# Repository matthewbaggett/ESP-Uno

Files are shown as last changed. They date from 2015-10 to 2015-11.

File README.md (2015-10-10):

# ESPUno - A dirty ESP8266 Arduino Uno clone

Using an ESP8266 should be fun! These processors are cheap enough to be disposable, lets make that easier to achieve as a hobbist.

Features: 

+ 80/160Mhz ESP8266
+ 5 working ADC pins (A0 is the 0-1 volt ESP8266 ADC, A1-A5 are provided by an i2c ADC controller (ADS1115) 
+ Pin 13 LED still present, tied to SCLK/GPIO6
+ LiPo cell support on-board! MCP73831 Charger circuit, TSP61200 Boost converter (shamelessly stolen from a [Sparkfun reference design](https://www.sparkfun.com/products/11231)) 
+ 3.3V regulator ([AMS1117](http://www.aliexpress.com/premium/ams1117.html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))
+ All the associated recommended pullups as per the [Arduino ESP8266 project](https://github.com/esp8266/Arduino) ([Schematic](https://github.com/esp8266/Arduino/blob/esp8266/docs/ESP_improved_stability.png))
+ Built-in USB programmer ([FTDI FT232R](http://www.aliexpress.com/premium/FT232R.html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)) similar to how the Arduinos have.
+ Mini-USB port. They're easier to get hold of, for me, and the full-size USB connector tends to short out cheaply made boards that ride up on top of the Arduino. Also should help reduce the deck height of the board.
+ All of the parts that weren't restricted to being tiny ICs (Damn ADS1115, TSP61200, LMV358IDGKR) are massive 1206-size parts.
+ Lots of amusing LEDs along the top left corner/edge. In order: Charging/Power On/RX/TX/Pin 13 "L"
+ Flash and Reset pushbuttons.

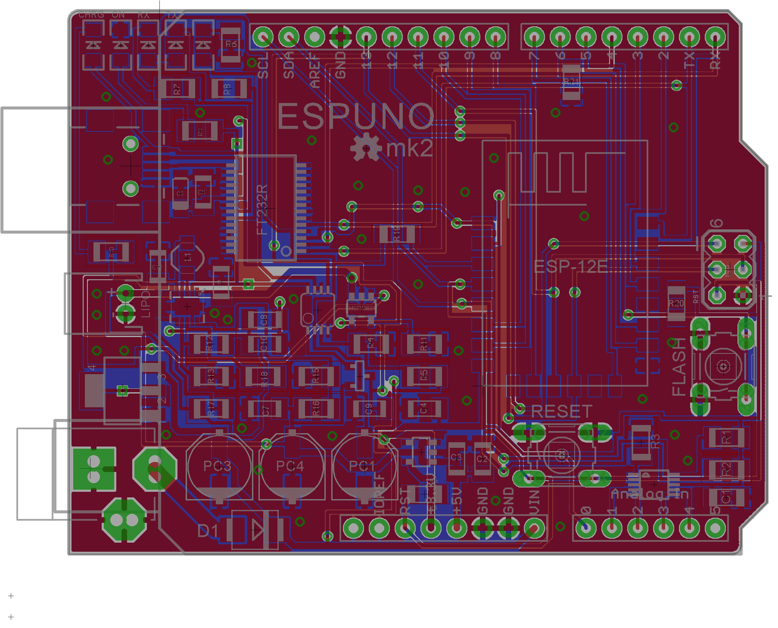
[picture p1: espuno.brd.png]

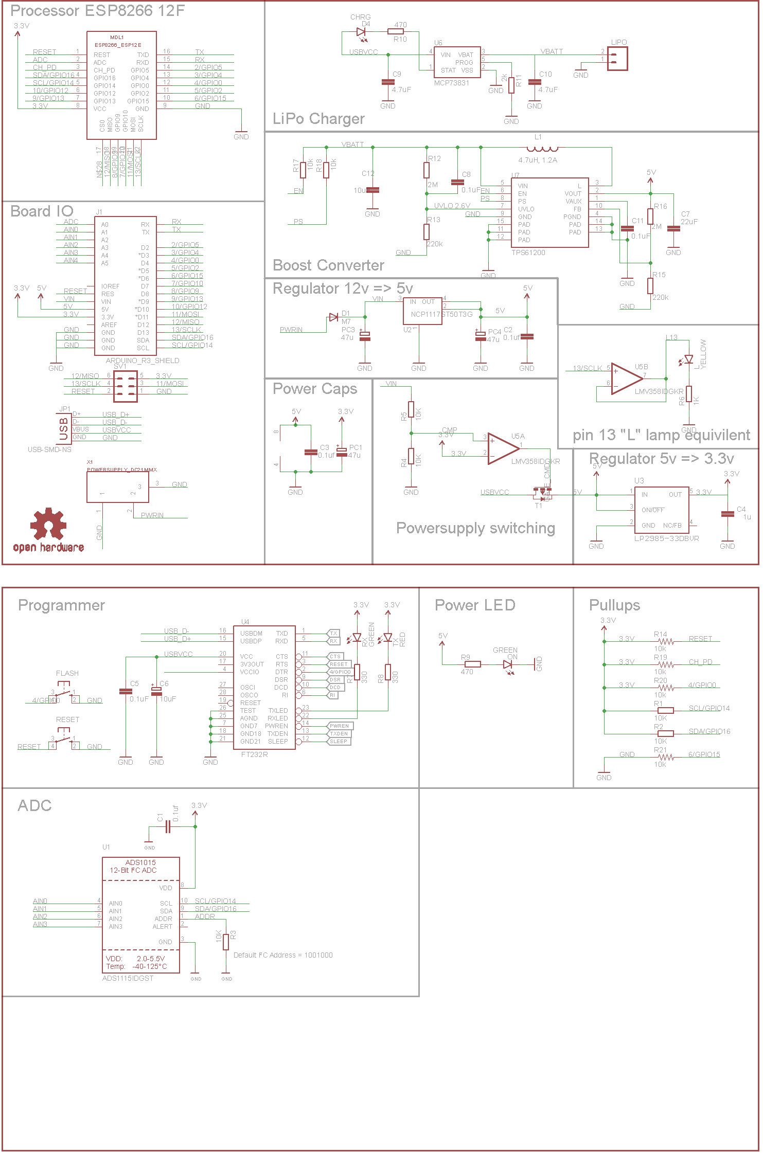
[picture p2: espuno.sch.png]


# Licence

<br />This work is licensed under a <a rel="license" href="http://creativecommons.org/licenses/by-nc/4.0/">Creative Commons Attribution-NonCommercial 4.0 International License</a>.

May be re-licenced on request.

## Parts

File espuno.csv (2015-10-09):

Part | Value | Device | Package | Description | DESIGNER | MF | MPN | OC_FARNELL | OC_NEWARK | PROD_ID | SKU | VERSION
C1 | 1µF | CAP_CERAMIC0805 | 0805 | Ceramic Capacitors
C2 | 100n | C-EUC1206K | C1206K | CAPACITOR, European symbol
C3 | 100n | C-EUC1206K | C1206K | CAPACITOR, European symbol
C4 | 1u | C-EUC1206K | C1206K | CAPACITOR, European symbol
C5 | 0.1uF | C-EUC1206K | C1206K | CAPACITOR, European symbol
C6 | 10uF | CPOL-EUSMCA | SMC_A | POLARIZED CAPACITOR, European symbol
C7 | 22uF | C-EUC1206K | C1206K | CAPACITOR, European symbol
C8 | 0.1uF | C-EUC1206K | C1206K | CAPACITOR, European symbol
C9 | 4.7uF | C-EUC1206K | C1206K | CAPACITOR, European symbol
C10 | 4.7uF | C-EUC1206K | C1206K | CAPACITOR, European symbol
C11 | 0.1uF | C-EUC1206K | C1206K | CAPACITOR, European symbol
C12 | 10uF | C-EUC1206K | C1206K | CAPACITOR, European symbol
D1 | M7 | DIODE-SMB | SMB | DIODE
D4 | CHRG | LED1206 | LED-1206 | LEDs
FLASH |  | 10-XX | B3F-10XX | OMRON SWITCH |  |  | B3F-1000 | 176432 | 36M3542
FRAME1 |  | FRAME-LETTERNO_PACKAGE | DUMMY | Schematic Frame | Nobody |  |  |  |  |  |  | v01
FRAME2 |  | FRAME-LETTERNO_PACKAGE | DUMMY | Schematic Frame | Nobody |  |  |  |  |  |  | v01
J1 | ARDUINO_R3_SHIELD | ARDUINO_R3_SHIELD | UNO_R3_SHIELD | Shield form compatible with the Arduino Uno R3.
JP1 | USB-SMD-NS | USB-SMD-NS | USB-MINIB-NOSTOP | USB Connectors
L | YELLOW | LED1206 | LED-1206 | LEDs
L1 | 4.7uH, 1.2A | INDUCTOR. | CDRH2D09 | Inductors
LIPO |  | M02JST-PTH-2 | JST-2-PTH | Standard 2-pin 0.1 header. Use with |  |  |  |  |  | CONN-09863 | PRT-09914
LOGO1 | OSHW-LOGOS | OSHW-LOGOS | OSHW-LOGO-S | Open Source Hardware Logo
MDL1 |  | ESP8266-12EESP8266-ESP12E | ESP8266-ESP12E | ESP8266-12E with additional I/O and GPIO04/05 corrected
ON | GREEN | LED1206 | LED-1206 | LEDs
PC1 | 47u | CPOL-EUD | PANASONIC_D | POLARIZED CAPACITOR, European symbol
PC3 | 47u | CPOL-EUD | PANASONIC_D | POLARIZED CAPACITOR, European symbol
PC4 | 47u | CPOL-EUD | PANASONIC_D | POLARIZED CAPACITOR, European symbol
R1 | 10K | R-EU_M1206 | M1206 | RESISTOR, European symbol
R2 | 10K | R-EU_M1206 | M1206 | RESISTOR, European symbol
R3 | 10K | R-EU_M1206 | M1206 | RESISTOR, European symbol
R4 | 10K | R-EU_M1206 | M1206 | RESISTOR, European symbol
R5 | 10K | R-EU_M1206 | M1206 | RESISTOR, European symbol
R6 | 1K | R-EU_M1206 | M1206 | RESISTOR, European symbol
R7 | 330 | R-EU_M1206 | M1206 | RESISTOR, European symbol
R8 | 330 | R-EU_M1206 | M1206 | RESISTOR, European symbol
R9 | 470 | R-EU_M1206 | M1206 | RESISTOR, European symbol
R10 | 470 | R-EU_M1206 | M1206 | RESISTOR, European symbol
R11 | 2k | R-EU_M1206 | M1206 | RESISTOR, European symbol
R12 | 2M | R-EU_M1206 | M1206 | RESISTOR, European symbol
R13 | 220k | R-EU_M1206 | M1206 | RESISTOR, European symbol
R14 | 10k | RESISTOR1206 | 1206 | Resistor
R15 | 220k | R-EU_M1206 | M1206 | RESISTOR, European symbol
R16 | 2M | R-EU_M1206 | M1206 | RESISTOR, European symbol
R17 | 10k | R-EU_M1206 | M1206 | RESISTOR, European symbol
R18 | 10k | R-EU_M1206 | M1206 | RESISTOR, European symbol
R19 | 10k | RESISTOR1206 | 1206 | Resistor
R20 | 10k | RESISTOR1206 | 1206 | Resistor
R21 | 10k | RESISTOR1206 | 1206 | Resistor
RESET |  | 10-XX | B3F-10XX | OMRON SWITCH |  |  | B3F-1000 | 176432 | 36M3542
RX | GREEN | LED1206 | LED-1206 | LEDs
SV1 |  | MA03-2 | MA03-2 | PIN HEADER |  |  |  | unknown | unknown
T1 | FDN340P | PMOSSOT23 | SOT-23 | MOS FET
TX | RED | LED1206 | LED-1206 | LEDs
U1 | ADS1115IDGST | ADC_ADS1015 | MSOP10 | ADS1015 - 12-bit 4-Channel I2C ADC with Internal PGA
U2 | NCP1117ST50T3G | MC33269ST-3.3T3 | SOT223 | Adjustable Output Low Dropout Voltage Regulator 800 mA
U3 | LP2985-33DBVR | LP2985-XXDBVR33 | SOT23-DBV | ULTRALOW-POWER 50-mA LOW-DROPOUT LINEAR REGULATORS
U4 | FT232R | FT232RLSSOP | SSOP28DB | USB UART
U5 | LMV358IDGKR | LMV358MMX | MSOP08 | Dual General Purpose, Low Voltage, Rail-to-Rail Output Operational Amplifiers
U6 | MCP73831 | MCP73831 | SOT23-5 | Microchip's MCP73831
U7 | TPS61200 | TPS61200 | QFN-10_PAD | DC to DC Booster
X1 | POWERSUPPLY_DC21MMX | POWERSUPPLY_DC21MMX | POWERSUPPLY_DC-21MM

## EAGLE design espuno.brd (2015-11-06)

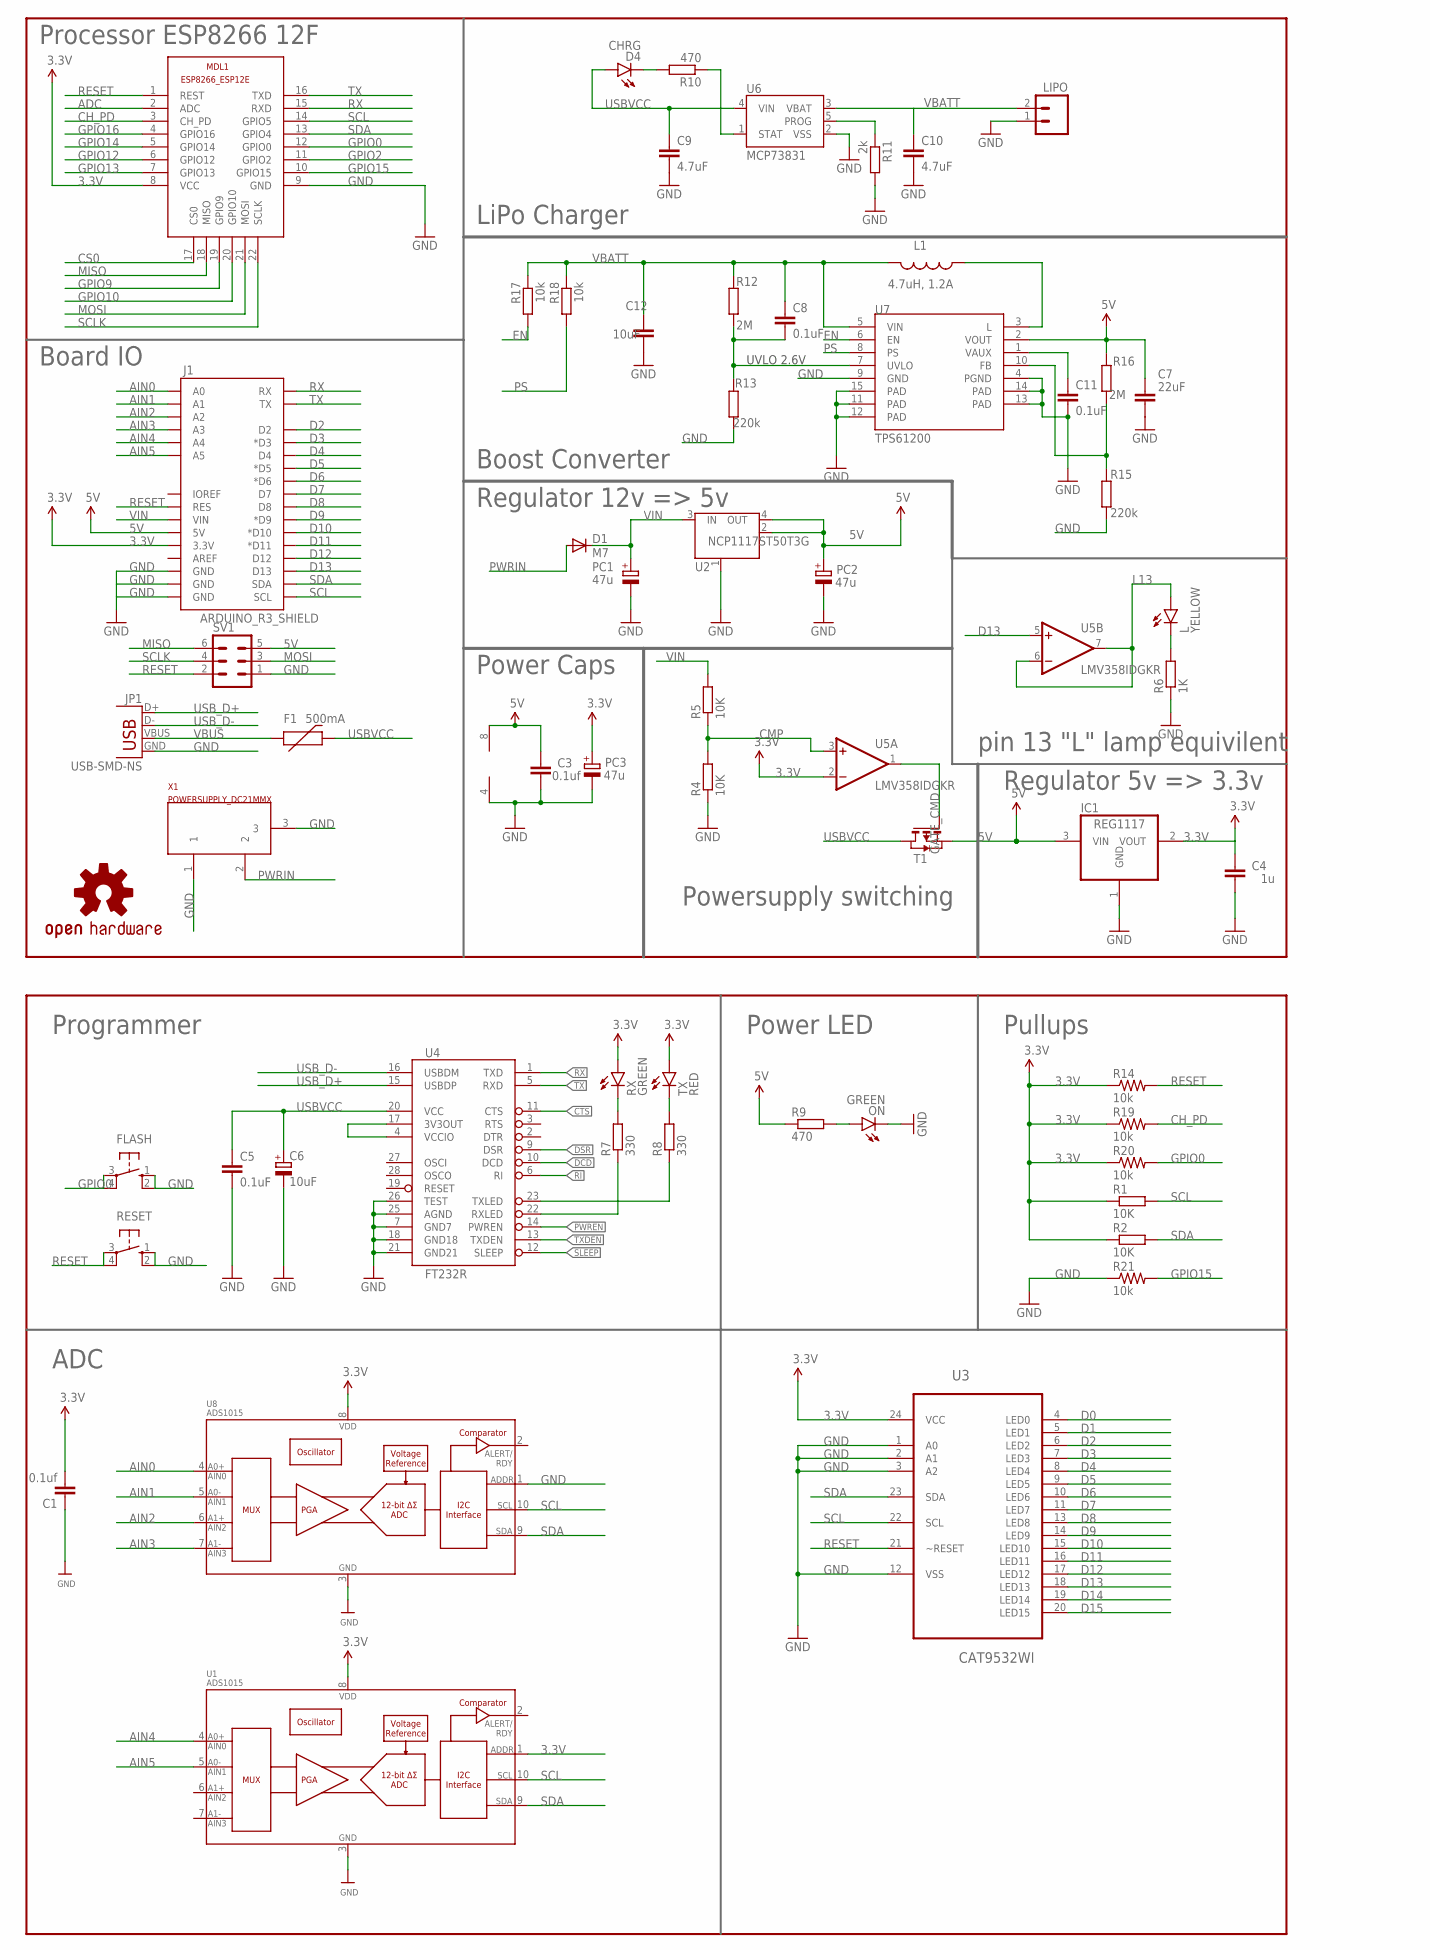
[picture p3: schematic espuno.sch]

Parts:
C1: 0.1uf; 1206
C3: 0.1uf; C1206K
C4: 1u; C1206K
C5, C8, C11: 0.1uF; C1206K
C6: 10uF; SMC_A
C7: 22uF; C1206K
C9, C10: 4.7uF; C1206K
C12: 10uF; C1206K
D1: M7; SMB
D4: CHRG; LED-1206
F1: 500mA; PTC-1206
FLASH: 10-XX; B3F-10XX
FRAME1, FRAME2: FRAME-LETTERNO_PACKAGE; DUMMY
IC1: REG1117; SOT223
J1: ARDUINO_R3_SHIELD; UNO_R3_SHIELD
JP1: USB-SMD-NS; USB-MINIB-NOSTOP
L: YELLOW; LED-1206
L1: 4.7uH, 1.2A; CDRH2D09
LIPO: M02JST-PTH-2; JST-2-PTH
LOGO1: OSHW-LOGOS; OSHW-LOGO-S
MDL1: ESP8266-12EESP8266-ESP12E; ESP8266-ESP12E
ON: GREEN; LED-1206
PC1, PC2, PC3: 47u; PANASONIC_D
R1, R2, R4, R5: 10K; M1206
R6: 1K; M1206
R7, R8: 330; M1206
R9, R10: 470; M1206
R11: 2k; M1206
R12, R16: 2M; M1206
R13, R15: 220k; M1206
R14, R19, R20, R21: 10k; 1206
R17, R18: 10k; M1206
RESET: 10-XX; B3F-10XX
RX: GREEN; LED-1206
SV1: MA03-2
T1: FDN340P; SOT-23
TX: RED; LED-1206
U1, U8: ADS1015; MSOP10
U2: NCP1117ST50T3G; SOT223
U3: CAT9532WI; SOIC127P1031X265-24N
U4: FT232R; SSOP28DB
U5: LMV358IDGKR; MSOP08
U6: MCP73831; SOT23-5
U7: TPS61200; QFN-10_PAD
X1: POWERSUPPLY_DC21MMX; POWERSUPPLY_DC-21MM

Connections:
3.3V: C1.2, C4.2, IC1.2 (VOUT), J1.3.3V, MDL1.8 (VCC), PC3.+, R1.1, R2.1, R14.1, R19.1, R20.1, RX.A, TX.A, U1.1 (ADDR), U1.8 (VDD), U3.24 (VCC), U5.2 (-IN), U8.8 (VDD)
5V: C3.2, C7.1, IC1.3 (VIN), J1.5V, PC2.+, R9.1, R16.2, SV1.5, T1.2 (S), U2.2 (OUT), U2.4 (OUT), U5.8 (V+), U7.2 (VOUT)
ADC: MDL1.2 (ADC)
AIN0: J1.A0, U8.4 (AIN0)
AIN1: J1.A1, U8.5 (AIN1)
AIN2: J1.A2, U8.6 (AIN2)
AIN3: J1.A3, U8.7 (AIN3)
AIN4: J1.A4, U1.4 (AIN0)
AIN5: J1.A5, U1.5 (AIN1)
CH_PD: MDL1.3 (CH_PD), R19.2
CMP: R4.2, R5.1, U5.3 (+IN)
CS0: MDL1.17 (CS0)
CTS: U4.11 (CTS)
D0: U3.4 (LED0)
D1: U3.5 (LED1)
D2: J1.D2, U3.6 (LED2)
D3: J1.D3 (*D3), U3.7 (LED3)
D4: J1.D4, U3.8 (LED4)
D5: J1.D5 (*D5), U3.9 (LED5)
D6: J1.D6 (*D6), U3.10 (LED6)
D7: J1.D7, U3.11 (LED7)
D8: J1.D8, U3.13 (LED8)
D9: J1.D9 (*D9), U3.14 (LED9)
D10: J1.D10 (*D10), U3.15 (LED10)
D11: J1.D11 (*D11), U3.16 (LED11)
D12: J1.D12, U3.17 (LED12)
D13: J1.D13, U3.18 (LED13), U5.5 (+IN)
D14: U3.19 (LED14)
D15: U3.20 (LED15)
DCD: U4.10 (DCD)
DSR: U4.9 (DSR)
EN: R17.2, U7.6 (EN)
FB: R15.2, R16.1, U7.10 (FB)
GATE_CMD: T1.3 (G), U5.1 (OUT)
GND: C1.1, C3.1, C4.1, C5.2, C6.-, C7.2, C9.2, C10.2, C11.2, C12.2, FLASH.1 (S), FLASH.2 (S1), IC1.1 (GND), J1.GND@0 (GND), J1.GND@1 (GND), J1.GND@2 (GND), JP1.GND, LIPO.1, MDL1.9 (GND), ON.C, PC1.-, PC2.-, PC3.-, R4.1, R6.1, R11.2, R13.1, R15.1, R21.1, RESET.1 (S), RESET.2 (S1), SV1.1, U1.3 (VSS), U2.1 (GND/ADJ), U3.1 (A0), U3.2 (A1), U3.3 (A2), U3.12 (VSS), U4.7 (GND7), U4.18 (GND18), U4.21 (GND21), U4.25 (AGND), U4.26 (TEST), U5.4 (V-), U6.2 (VSS), U7.4 (PGND), U7.9 (GND), U7.11 (PAD), U7.12 (PAD), U7.13 (PAD), U7.14 (PAD), U7.15 (PAD), U8.1 (ADDR), U8.3 (VSS), X1.1, X1.3
GPIO0: FLASH.3, FLASH.4 (P1), MDL1.12 (GPIO0), R20.2
GPIO2: MDL1.11 (GPIO2)
GPIO9: MDL1.19 (GPIO9)
GPIO10: MDL1.20 (GPIO10)
GPIO12: MDL1.6 (GPIO12)
GPIO13: MDL1.7 (GPIO13)
GPIO14: MDL1.5 (GPIO14)
GPIO15: MDL1.10 (GPIO15), R21.2
GPIO16: MDL1.4 (GPIO16)
L13: L.A, U5.6 (-IN), U5.7 (OUT)
MISO: MDL1.18 (MISO), SV1.6
MOSI: MDL1.21 (MOSI), SV1.3
unnamed: ON.A, R9.2
unnamed: L.C, R6.2
unnamed: R7.2, RX.C
unnamed: R8.2, TX.C
unnamed: L1.P$1 (1), U7.3 (L)
unnamed: C11.1, U7.1 (VAUX)
unnamed: R7.1, U4.22 (RXLED)
unnamed: D4.C, R10.2
unnamed: R8.1, U4.23 (TXLED)
unnamed: U4.4 (VCCIO), U4.17 (3V3OUT)
unnamed: R11.1, U6.5 (PROG)
unnamed: R10.1, U6.1 (STAT)
PS: R18.2, U7.8 (PS)
PWREN: U4.14 (PWREN)
PWRIN: D1.A, X1.2
RESET: J1.RES, MDL1.1 (REST), R14.2, RESET.3, RESET.4 (P1), SV1.2, U3.21 (~RESET)
RI: U4.6 (RI)
RX: J1.RX, MDL1.15 (RXD), U4.1 (TXD)
SCL: J1.SCL, MDL1.14 (GPIO5), R1.2, U1.10 (SCL), U3.22 (SCL), U8.10 (SCL)
SCLK: MDL1.22 (SCLK), SV1.4
SDA: J1.SDA, MDL1.13 (GPIO4), R2.2, U1.9 (SDA), U3.23 (SDA), U8.9 (SDA)
SLEEP: U4.12 (SLEEP)
TX: J1.TX, MDL1.16 (TXD), U4.5 (RXD)
TXDEN: U4.13 (TXDEN)
USBVCC: C5.1, C6.+, C9.1, D4.A, F1.2, T1.1 (D), U4.20 (VCC), U6.4 (VIN)
USB_D+: JP1.D+, U4.15 (USBDP)
USB_D-: JP1.D-, U4.16 (USBDM)
UVLO: C8.2, R12.1, R13.2, U7.7 (UVLO)
VBATT: C8.1, C10.1, C12.1, L1.P$2 (2), LIPO.2, R12.2, R17.1, R18.1, U6.3 (VBAT), U7.5 (VIN)
VBUS: F1.1, JP1.VBUS
VIN: D1.C, J1.VIN, PC1.+, R5.2, U2.3 (IN)

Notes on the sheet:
UVLO 2.6V
Programmer
ADC
Power LED
Pullups
pin 13 "L" lamp equivilent
Processor ESP8266 12F
Board IO
Regulator 5v => 3.3v
Powersupply switching
Power Caps
Regulator 12v => 5v
Boost Converter
LiPo Charger

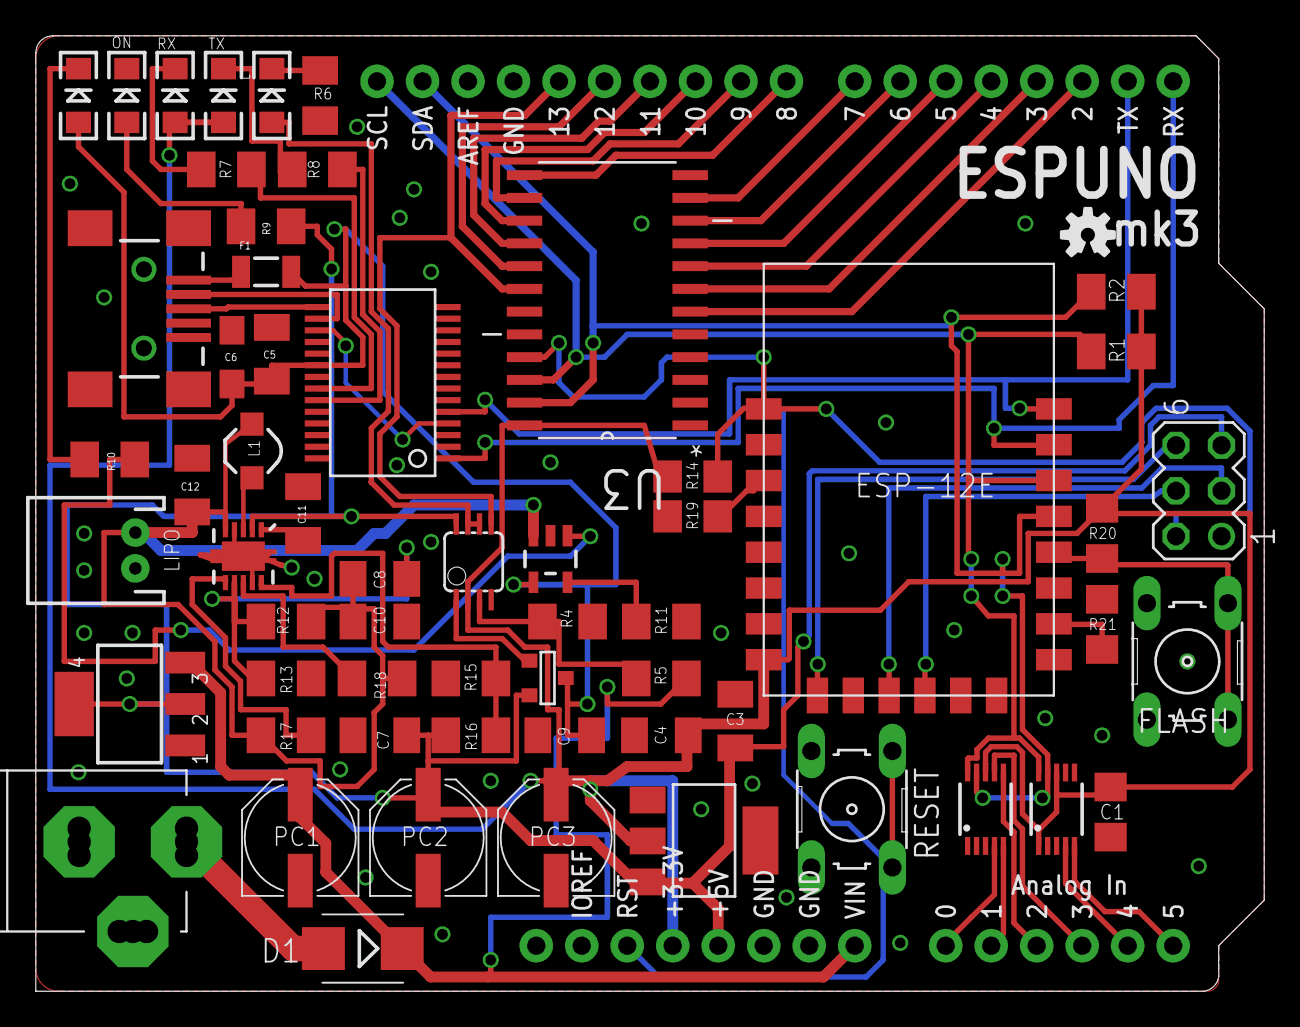
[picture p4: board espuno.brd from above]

Board: 2 copper layers, 68.6 x 53.3 mm, 63 parts (0 on the bottom side), 58 nets.

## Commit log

2015-08-27 Added LIPO parts, use more 0805 resistors/caps and 1206 LEDs instead of f&cking 0402s
    [espuno.brd, espuno.sch]
2015-09-04 Fixing layout of labels, adding ESPUNO text, slight layout tweaks to make slightly more pleasing.
    [espuno.brd, espuno.sch]
2015-09-10 Adding BOM
    [espuno.csv]
2015-10-07 Espuno Mk2, with bigass 1206's for errything
    [espuno.brd, espuno.sch]
2015-10-09 removed because old
    [espuno.csv]
2015-10-09 Mk2 revision complete. Tidied schematics and board. Added pullups.
    [espuno.brd, espuno.sch]
2015-10-09 Move some labels, change 'CHARGING' into 'CHRG' for brevity
    [espuno.brd, espuno.sch]
2015-10-09 No changes?
    [espuno.brd]
2015-10-09 Revise which size C1 is
    [espuno.brd, espuno.sch]
2015-10-09 Change 100nf => 0.1uf
    [espuno.brd, espuno.sch]
2015-10-10 Move i2c pullup resistors to Pullups section of schematic
    [espuno.brd, espuno.sch]
2015-10-10 Better rear silkscreen layer
    [espuno.brd]
2015-11-04 Fix bug with TX/RX switched, renumber PC1,PC3,PC4 to be PC1-3 in order of decreasing voltage rail.
    [espuno.brd, espuno.sch]
2015-11-04 Change puny 3.3v regulator for a 800mA-1A regulator. Rearrangements to make space, remove redundent capacitor
    [espuno.brd, espuno.sch]
2015-11-04 Use two ADS1015's and a CAT9531 to interface with the outside world.
    [espuno.brd, espuno.sch]
2015-11-05 move adc bits up a bit away from the port
    [espuno.brd, espuno.sch]
2015-11-06 Make the FT232R consume its own 3.3v so I can test it by merely attaching USB.
    [espuno.brd, espuno.sch]
2015-11-06 Add 500mA fuse
    [espuno.brd, espuno.sch]

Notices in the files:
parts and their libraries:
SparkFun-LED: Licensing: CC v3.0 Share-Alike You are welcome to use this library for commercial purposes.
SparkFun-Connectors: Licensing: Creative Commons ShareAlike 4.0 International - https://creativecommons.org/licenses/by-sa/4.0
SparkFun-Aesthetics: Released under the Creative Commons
